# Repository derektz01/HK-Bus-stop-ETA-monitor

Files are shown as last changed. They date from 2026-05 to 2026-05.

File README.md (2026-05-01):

# HK Bus Stop ETA Monitor

Real-time Hong Kong bus arrival time display running on the **Waveshare ESP32-S3-Touch-LCD-4.3** — an all-in-one board with a 4.3" 800×480 IPS panel, capacitive touch (GT911), 16 MB flash, and 8 MB OPI PSRAM. ([https://www.waveshare.com/esp32-s3-touch-lcd-4.3.htm](https://www.waveshare.com/esp32-s3-touch-lcd-4.3.htm))

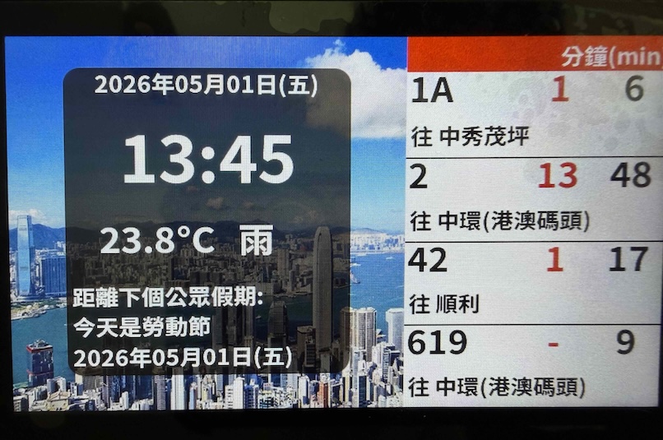
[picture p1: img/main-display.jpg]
Main Display


## Overview

This project turns the Waveshare ESP32-S3-Touch-LCD-4.3 board into a desk-side bus stop electronic arrival board. The UI is built with LVGL 8.4 (SquareLine Studio) directly on the on-board LCD — no external Nextion HMI required. All configuration lives on a captive web portal hosted by the device itself.

It fetches live ETA data from:

- KMB (九巴) — `data.etabus.gov.hk`
- Citybus (城巴) — `rt.data.gov.hk` (V1 batch endpoint)

Background changes through the day (day / sunset / night), and the panel can be put on a programmable sleep schedule with touch-wake.

The display shows:

- Current time, date, and weekday
- Hong Kong public holiday countdown
- Real-time temperature + weather icon (Open-Meteo)
- Up to 4 bus routes per page with smart ETA (`-`, `<1`, or minutes)
- Auto slideshow every 5 seconds; tap the right-side hotspot to advance manually

## Features

- **Multi-stop ETA** — pick any number of KMB and Citybus stops via the web UI; the device cycles through every selected stop on the slideshow.
- **Captive web settings portal** — Wi-Fi, stops, schedule, and language all configurable from a browser (`/api/config`, `/api/reboot` in [src/WebPortal.cpp](src/WebPortal.cpp)).
- **Map-based stop picker** — interactive Leaflet + OpenStreetMap view with all KMB / CTB stops as clickable pins. **No API key required**, all assets bundled in LittleFS.
- **Live "routes at this stop" view** — ⓘ button on every selected stop opens a modal listing every route that serves that stop, with destination. Live for KMB (via `/stop-eta/{id}`), cached for CTB.
- **Multi-language UI** — settings page in English or 繁體中文; auto-detects browser locale on first visit, persists choice in `localStorage`. Bus stop names always come from the API in Chinese (the underlying data).
- **Programmable sleep schedule** — repeating "wake at" / "sleep at" tasks per weekday; the device deep-sleeps between scheduled windows. Touch-wake grace period (1 / 2 / 5 / 10 / 30 minutes) lets the user glance at the screen mid-sleep.
- **Dynamic Citybus route/stop discovery** — no hardcoded route lists; the browser builds the full stop list once with a 60 s cooldown and a 2 h rate-limit gate to protect the upstream API.
- **AP-mode fallback** — device starts its own Wi-Fi AP if it can't join the configured network ([src/Wireless.cpp](src/Wireless.cpp)).
- **Smart ETA display** — `-` means arriving soon / not in service, `<1` means less than a minute, otherwise minutes. Both inbound and outbound directions shown when available.
- Routes auto-sorted by route number; destinations prefixed with `往` (toward) when present.
- Public holiday countdown loaded from `data/holiday.json`.
- NTP time sync (Hong Kong timezone, UTC+8).
- **PSRAM-bus optimised for the RGB panel** — internal-RAM ArduinoJson allocator, HTTP keep-alive for CTB, plain HTTP for KMB, field-filtered JSON parsing — all to keep the PSRAM bus quiet for the LCD scanout DMA so the panel doesn't drift during fetches.

## Hardware

- **Board**: [Waveshare ESP32-S3-Touch-LCD-4.3](https://www.waveshare.com/esp32-s3-touch-lcd-4.3.htm)
  - ESP32-S3-N16R8 (16 MB flash, 8 MB OPI PSRAM)
  - 4.3" 800×480 IPS panel via 16-bit RGB parallel interface
  - GT911 capacitive touch over I²C (INT on GPIO 4 — also the deep-sleep wake source)
  - CH422G IO expander (drives backlight, LCD reset, touch reset)
- **Power**: USB-C (5 V, ~400 mA)
- **No external display** — the LCD is on-board.

## Enclosure (3D-printed case)

A 3D-printable case with a desk stand has been designed for this build. The STEP sources are in the repo so you can adapt them in any CAD tool before slicing.

| Front | Back | Inside |
| --- | --- | --- |
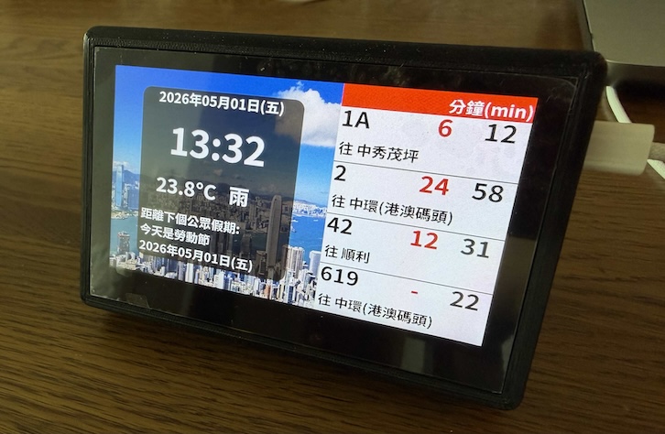
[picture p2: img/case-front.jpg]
Case front
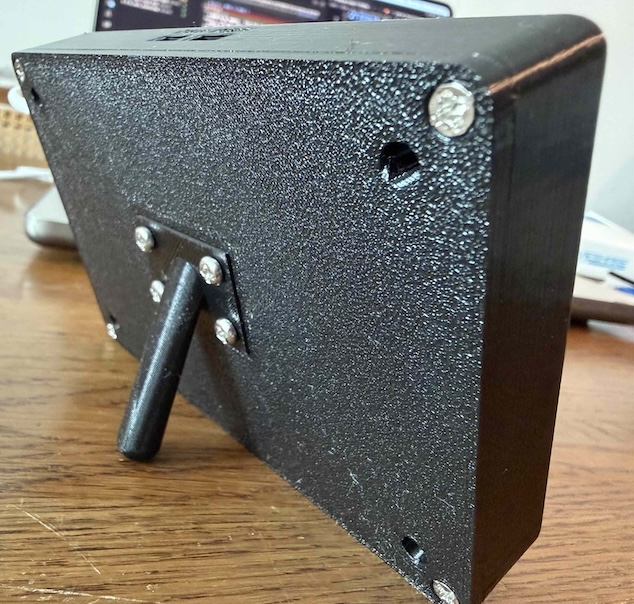
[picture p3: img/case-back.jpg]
Case back
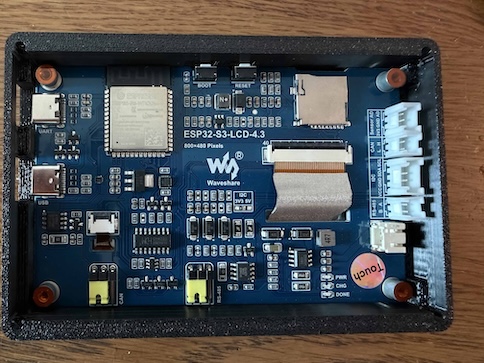
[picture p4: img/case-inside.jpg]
Inside
|  |  |  |

Download the STEP files from [`3D print/`](3D%20print/):

- [`ETA_Mon_Case.step`](3D%20print/ETA_Mon_Case.step) — main enclosure (front shell that holds the panel)
- [`ETA_Mon_Back_plate.step`](3D%20print/ETA_Mon_Back_plate.step) — rear plate covering the board
- [`ETA_Mon_Stand.step`](3D%20print/ETA_Mon_Stand.step) — desk stand

### Assembly hardware

You'll need a small set of screws to put it together:

- **4 × M2.5 × 6 mm Philips-head** — fix the Waveshare board to the back plate (the four mounting holes on the corners of the board)
- **8 × M3 × 4–5 mm flat-head countersunk** — clamp the front shell, back plate, and stand together

Any standard M2.5 / M3 hardware kit will have these. M3 × 4 mm or M3 × 5 mm both fit; longer than 5 mm risks bottoming out into the panel cavity.

## Repository Structure

```text
include/
└── esp_panel_board_custom_conf.h   # ESP32_Display_Panel board config
src/
├── main.cpp                # setup(), loop(), networkTask, webPortalTask
├── Display.cpp / .h        # LVGL widget glue (Update_Time, Update_Bus_List, ...)
├── lvgl_v8_port.cpp / .h   # LVGL ↔ ESP32_Display_Panel adapter
├── ui/                     # SquareLine Studio generated UI
│   ├── ui_Main.c           # Widget tree
│   ├── ui_font_NSTC*.c     # NotoSans TC fonts (28/44/80 px)
│   └── ui_img_*.c          # Background images (day / sunset / night)
├── BusData.cpp / .h        # KMB + Citybus ETA fetching
├── WeatherData.cpp / .h    # Open-Meteo weather
├── HolidayData.cpp / .h    # Holiday JSON loading + countdown
├── ConfigManager.cpp / .h  # Persisted config (Wi-Fi, stops, schedule)
├── Wireless.cpp / .h       # Wi-Fi STA + AP-mode fallback
├── WebPortal.cpp / .h      # HTTP server: /api/config, /api/reboot, static
├── Sleep.cpp / .h          # Deep-sleep scheduler + GT911 touch wake
├── JsonInternal.h          # Internal-RAM ArduinoJson allocator
└── Diagnostics.cpp / .h    # Heap_Log helper
data/
├── index.html              # Captive web settings portal
├── favicon.ico             # 32×32 favicon
├── leaflet.{js,css}        # Leaflet 1.9.4 (bundled, no CDN)
├── leaflet.markercluster.js
├── MarkerCluster*.css
├── config.json             # Runtime config (created from .template)
└── holiday.json            # 2026 Hong Kong public holidays
partitions_16MB_littlefs.csv  # Custom 16 MB partition (7 MB app × 2 + 2 MB FS)
```

## Dependencies

PlatformIO libraries (pinned in `platformio.ini`):

- [`ESP32_Display_Panel`](https://github.com/esp-arduino-libs/ESP32_Display_Panel) — board / panel / touch driver
- [`ESP32_IO_Expander`](https://github.com/esp-arduino-libs/ESP32_IO_Expander) — CH422G driver
- `esp-arduino-libs/esp-lib-utils @ ^0.3.0`
- `lvgl/lvgl @ ^8.4.0`
- `bblanchon/ArduinoJson @ ^7.2.0`

## Configuration

Everything except the AP credentials is configured at runtime through the captive web portal — see [TUTORIAL.md](TUTORIAL.md) for a full walkthrough.

### Bootstrap config (one-time, before first flash)

Before flashing, seed the device with at least the **AP credentials** so you can reach the captive portal when it falls back to AP mode.

1. Rename the template:

   ```bash
   cp data/config.json.template data/config.json
   ```

2. Edit `data/config.json`:

   ```jsonc
   {
     "wifi": {
       "ssid": "YOUR_WIFI_SSID",         // optional — set later in the portal
       "password": "YOUR_WIFI_PASSWORD"  // optional
     },
     "ap": {
       "ssid": "BusETAMonitor-AP",       // REQUIRED
       "password": "12345678"            // REQUIRED — ≥ 8 characters
     },
     "stops": {
       "kmb": [],                        // optional — pick stops in the portal
       "ctb": []
     },
     "sleep_schedule": {
       "wake_tasks": [],                 // optional — set in the portal
       "sleep_tasks": [],
       "grace_period_minutes": 5
     }
   }
   ```

3. Upload to LittleFS:

   ```bash
   pio run -t uploadfs
   ```

   The same command also uploads `index.html`, `holiday.json`, the Leaflet bundle, and the favicon — re-run any time you edit anything under `data/`.

> `data/config.json` is your local secrets file (it can hold your home Wi-Fi password). It is **not** intended to be committed to the repo — only `data/config.json.template` should be tracked.

### First boot

If the device cannot join the saved Wi-Fi (or none is configured), it falls back to AP mode. Connect your phone or laptop to the AP advertised by the device, then open `http://192.168.4.1` in a browser.

Once the device is on your home Wi-Fi, the same page is reachable at the device's IP, which the LCD displays in a scrolling banner for 2 minutes after every boot.

## Build & Upload

```bash
# 1. Upload data/ to LittleFS (settings page, leaflet, favicon, holidays)
pio run -t uploadfs

# 2. Build & upload firmware
pio run -t upload

# 3. Build only
pio run

# Optional — wipe flash (e.g. after changing the partition table)
pio run -t erase
```

The custom partition table `partitions_16MB_littlefs.csv` provides 7 MB per app slot (dual OTA) + ~2 MB LittleFS. If you change it, run `pio run -t erase` once before the next upload so the bootloader re-reads the partition map.

## Notes

- Slideshow advances every **5 seconds**. Tap the right-side hotspot on the panel to advance manually.
- Wi-Fi info banner shows on the LCD for **2 minutes** after every boot, then auto-hides.
- If Wi-Fi fails, the board keeps running with the last cached ETAs; weather + ETA fetches resume automatically when the link returns.
- Holiday display refreshes once per hour; backgrounds switch at 06:00 (day), 17:00 (sunset), 18:30 (night).
- Weather refreshes every 30 minutes; bus ETAs every 45 seconds.
- The deep-sleep scheduler wakes from either a configured timer or a screen touch (GT911 INT on GPIO 4).

## License

This project is released under the **Creative Commons Attribution-NonCommercial 4.0 International** licence ([CC BY-NC 4.0](https://creativecommons.org/licenses/by-nc/4.0/)).

You are free to:

- **Use, copy, modify, and redistribute** the source, the 3D-printable STEP files, and the documentation,
- for **personal, educational, and other non-commercial** purposes,
- as long as you give appropriate credit (link back to this repo).

You **may not** use this work — in whole or in part — for **commercial** purposes (selling assembled units, paid services built on this code, or any other commercial offering) without prior written permission from the author. If you'd like to discuss a commercial use, please open an issue first.

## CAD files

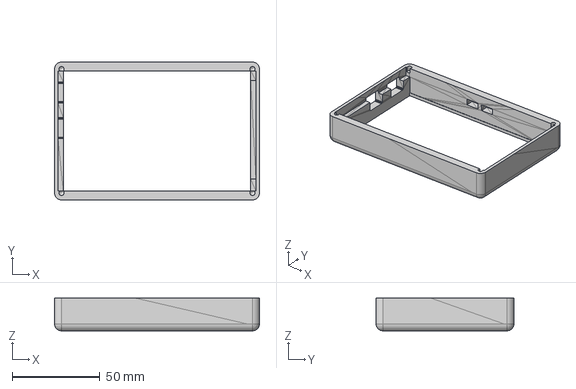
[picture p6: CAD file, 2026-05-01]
3D print/ETA_Mon_Case.step
116.5 x 78.4 x 18.6 mm

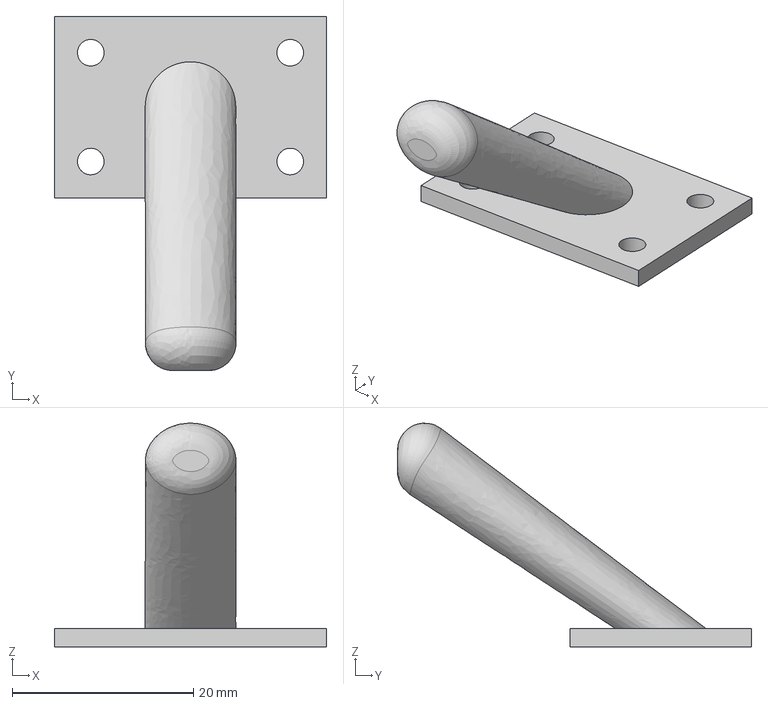
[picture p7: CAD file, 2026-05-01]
3D print/ETA_Mon_Stand.step
30.0 x 39.1 x 24.7 mm

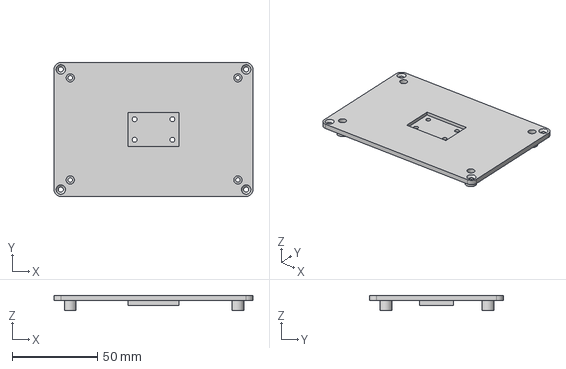
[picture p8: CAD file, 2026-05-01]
3D print/ETA_Mon_Back_plate.step
116.5 x 78.4 x 9.00 mm

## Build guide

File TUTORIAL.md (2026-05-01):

# Web Settings Page — User Guide

A walkthrough of the captive web portal used to configure the HK Bus ETA Monitor: language, Wi-Fi, the stop list cache, three ways to pick bus stops, the routes-at-stop view, the sleep schedule, save / reboot, and the rebuild cooldown / rate-limit gate.

---

## 1. Opening the settings page

The device serves the settings page on port 80 in both Wi-Fi modes:

- **First boot or after a Wi-Fi join failure** — the device falls back to AP mode (see [src/Wireless.cpp](src/Wireless.cpp)). Connect your phone or laptop to the AP advertised by the device, then open `http://192.168.4.1`.
- **Normal operation** — the device joins your home Wi-Fi as a station. Open `http://<device-ip>` (the IP appears on the device's LCD — see below).

### Finding the IP on the LCD

The firmware shows a **scrolling Wi-Fi info banner** on the LCD for the first **2 minutes** after every boot:

- **STA mode**: `WiFi:<ssid>  IP:<ip>`
- **AP mode**: `AP:<ssid>  P:<password>  IP:<ip>`

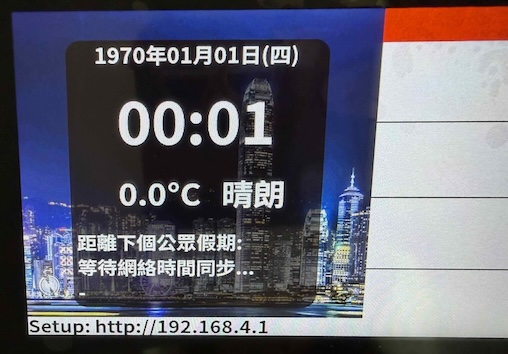
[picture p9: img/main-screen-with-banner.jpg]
Device LCD showing the Wi-Fi info banner


After 2 minutes the banner disappears so it doesn't clutter the ETA display. If you miss it, just power-cycle the device — the banner reappears for another 2 minutes after every boot.

You should see the page below.

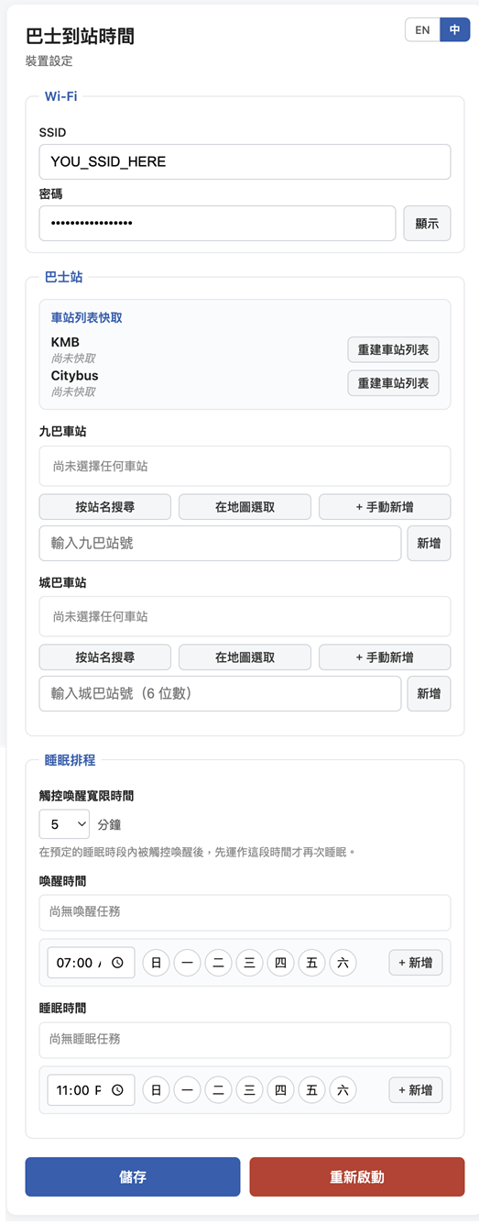
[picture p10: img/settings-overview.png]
Settings page overview


---

## 2. Switching language

The top-right of the card has a small **EN / 中** toggle. The page auto-detects your browser's language on first visit (anything starting with `zh` → 繁體中文, otherwise English) and persists your choice in `localStorage`.

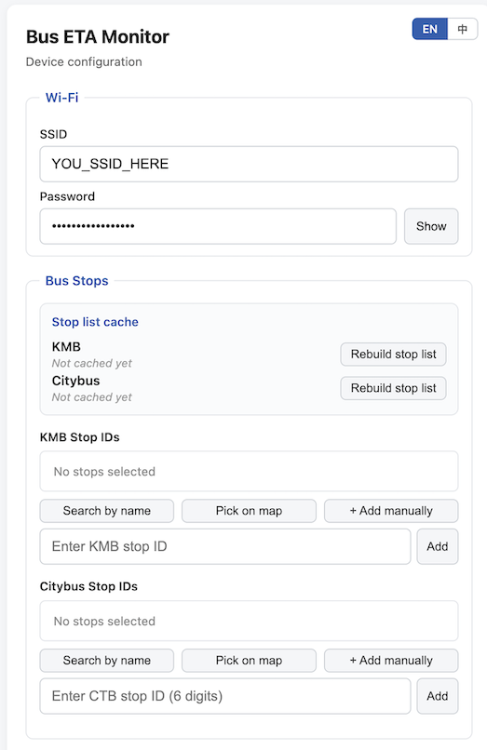
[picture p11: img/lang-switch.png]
Language switcher in the top-right of the card


> Bus stop names are **not** translated — they always come from the operator's API in Chinese (the source field is `name_tc`). Only the UI chrome flips when you switch language.

---

## 3. Wi-Fi setup

Fill in the **SSID** and **Password** of the network you want the device to join. Click **Show** next to the password to reveal what you typed; click **Hide** to mask it again.

> Wi-Fi changes do **not** take effect immediately — you must press **Save** and then **Reboot** before the device tries the new credentials.

---

## 4. Stop list cache

> ⚠️ **Wi-Fi (STA) mode is required to build the cache.** The cache build runs entirely in **your browser** — it fetches stop data straight from `data.etabus.gov.hk` and `rt.data.gov.hk`, not through the device. While the device is in **AP mode**, your phone or laptop has no path to the public internet, so the rebuild will fail (you'll see a CORS-looking error in the console; it's actually `HTTP 403` from the upstream gateway).
>
> **First-time setup flow**:
>
> 1. Complete [§3 Wi-Fi setup](#3-wi-fi-setup) — enter your home Wi-Fi SSID + password.
> 2. Click **Save**, then click **Reboot** ([§10](#10-rebooting-the-device)).
> 3. After the device comes back, the LCD banner ([§1](#1-opening-the-settings-page)) shows the new STA IP. Reconnect a browser on the **same home Wi-Fi** to that IP.
> 4. *Now* you can press **Rebuild stop list** here.

A separate **Stop list cache** card sits at the top of the Bus Stops section. It shows, at a glance:

- Whether the cache is built for each operator
- The total stop count and last-built timestamp
- A **Rebuild stop list** button per operator with the same 60 s cooldown and 2 h rate-limit gate (see §8)

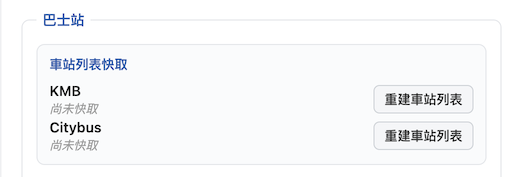
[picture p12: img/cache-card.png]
Stop list cache card


To use search or map-based stop picking, you need the cache built. KMB ships its full stop list at one endpoint (~6,800 stops, ~5 s build); CTB has no single endpoint, so the page builds it in three phases:

1. Fetch the route list (`/route/CTB`)
2. For each route × direction, fetch the route-stop list
3. For each unique stop, fetch the stop name + coordinates + per-route metadata

Expect CTB's first build to take a few minutes. Watch progress in the per-row status line.

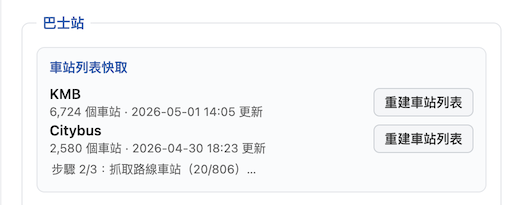
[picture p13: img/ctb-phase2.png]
CTB rebuild — Phase 2/3 in progress


The cache is stored in your browser's `localStorage` — it's a one-time cost per browser. Both caches now also carry stop coordinates (used by the map view) and CTB carries per-stop route info (used by the routes-at-stop view).

---

## 5. Picking bus stops

Each operator (KMB and Citybus) has the same row of three buttons under its label:

| Button | What it does |
| --- | --- |
| **Search by name** | Type any part of the Chinese stop name; live results from the cache. |
| **Pick on map** | Open an interactive map — pan / zoom, tap any pin to add. |
| **+ Add manually** | Type a known stop ID directly. Useful if you copied it from a URL. |

You can mix all three. Selected stops appear in the list above the buttons; click the red **×** on a row to remove a stop, click **ⓘ** to view the routes that serve it (see §6).

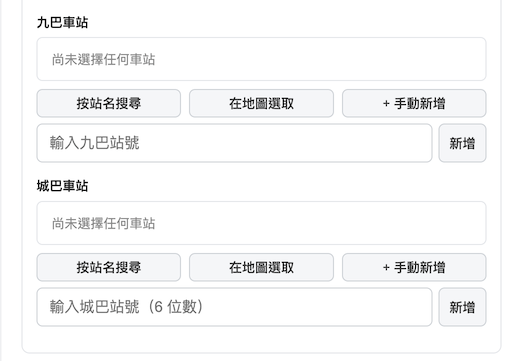
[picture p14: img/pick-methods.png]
Three pick methods, all visible


### 5a. Search by name

Open the search panel with **Search by name**, type any substring of the Chinese stop name, click any row to add.

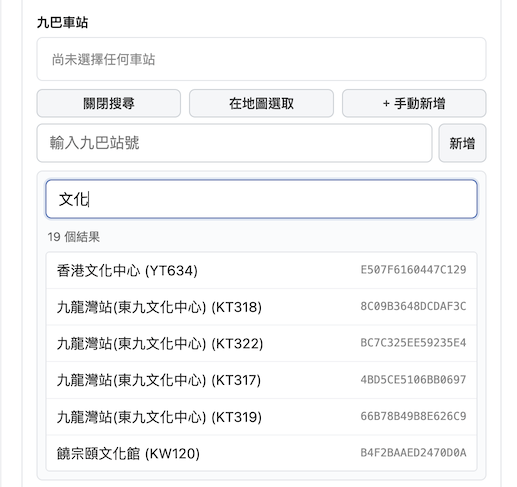
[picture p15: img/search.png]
KMB search results


You can add **as many stops as you want** for both KMB and Citybus — the device cycles through every selected stop on the slideshow.

### 5b. Pick on map (new)

Open with **Pick on map**. The map opens centred on Hong Kong with all stops as clustered pins (numbered cluster bubbles when zoomed out, individual pins when zoomed in). Tap a pin → a popup shows the stop name and ID with **Add this stop** and **View routes** buttons.

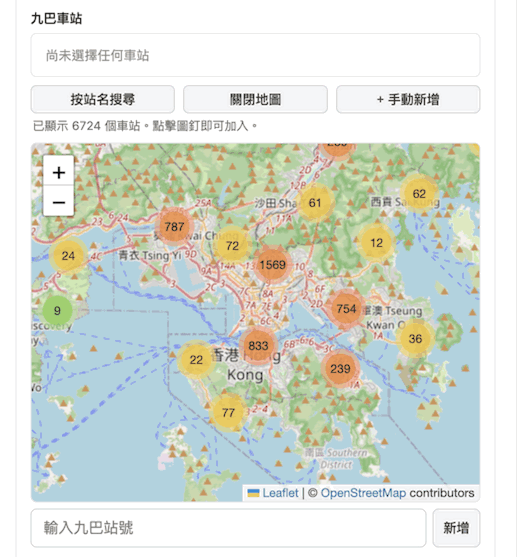
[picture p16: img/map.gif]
Map picker


The map uses Leaflet + OpenStreetMap tiles — **no API key required**, but the browser does need internet for the tile downloads. The Leaflet library itself is bundled in LittleFS.

> Already-selected stops appear in green on the map; unselected pins are blue. If tiles fail to load (e.g. you're connected only to the device's AP), a banner appears suggesting you fall back to **Search by name**.

### 5c. Add manually

Click **+ Add manually** under the operator section, type the stop ID, click **Add**.

- KMB IDs look like `904DEAF7441E3BB8` (16-char hex).
- CTB IDs are 6 digits, e.g. `001027`.

Manually-added stops show "(unresolved)" until the relevant cache is built — but they still work; the firmware queries by ID, not by name.

---

## 6. Viewing routes for a stop (new)

Each row in your selected-stops list has an **ⓘ** button (between the stop name and the red **×**). Click it to see every route that serves that stop, with destination.

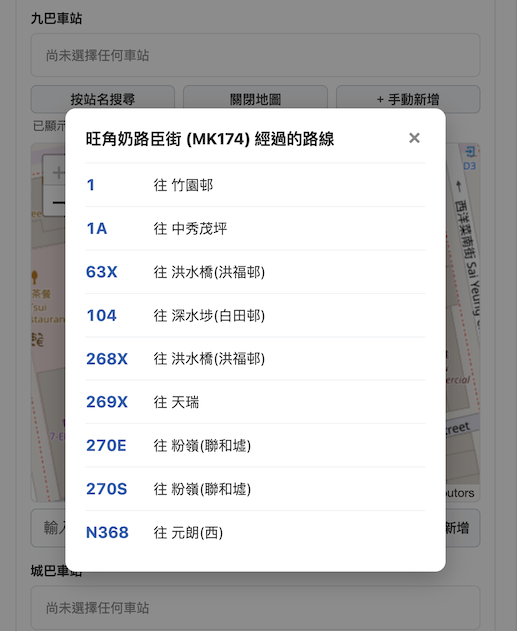
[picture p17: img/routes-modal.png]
View-routes modal


- For **KMB**, this fetches `/v1/transport/kmb/stop-eta/<id>` live, so the route list reflects current service.
- For **CTB**, this reads from the cache built earlier (CTB has no per-stop ETA endpoint that returns routes; you need the cache up-to-date — if it isn't, the modal tells you to rebuild first).

The same modal opens from the map popup's **View routes** button.

---

## 7. Sleep schedule (new)

A separate **Sleep Schedule** fieldset configures when the device deep-sleeps and wakes:

- **Touch-wake grace period** — when you tap the screen during a scheduled sleep window, the device wakes up and runs for this long before re-sleeping. Choices: 1 / 2 / 5 / 10 / 30 minutes.
- **Wake at** — list of repeating times the device should wake. Each task is `HH:MM` plus a set of weekdays (日 一 二 三 四 五 六).
- **Sleep at** — list of repeating times the device should enter deep sleep.

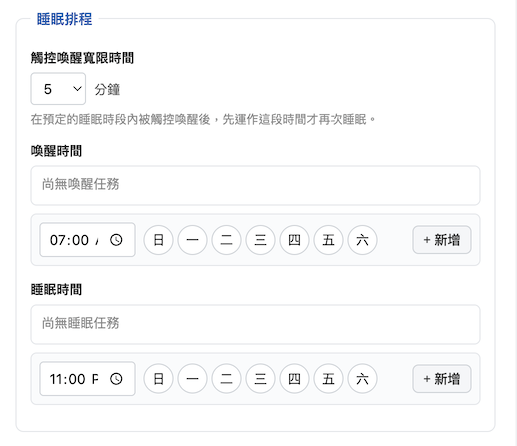
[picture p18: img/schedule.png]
Sleep schedule UI


Click the day circles to toggle weekdays (blue = active). Click **+ Add** to commit a task to the list; click the red **×** on a row to remove it.

### How the schedule is interpreted

The device computes the most recent past sleep-task and the most recent past wake-task. If the most recent event was a sleep, it deep-sleeps until the next wake-task time. If the most recent event was a wake, it runs until the next sleep-task time.

Touch-wake during a sleep window grants you the configured grace period before the device re-sleeps — handy for a quick glance.

> Schedule changes do **not** require a reboot — they're picked up on the next loop tick. Wi-Fi changes still do.

---

## 8. Rebuild cooldown and rate-limit gate

The KMB and Citybus APIs both rate-limit aggressive callers. The page has two protections.

### 60-second cooldown

After every rebuild — successful or failed — the **Rebuild stop list** button is disabled for 60 seconds and shows a live countdown:

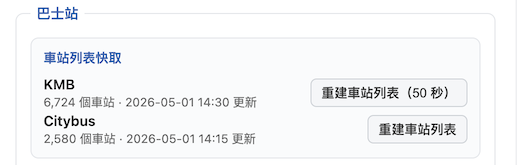
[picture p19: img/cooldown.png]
Rebuild button in cooldown


This applies to KMB and CTB independently.

### 2-hour cache-age gate

If you click **Rebuild stop list** while the cache is younger than 2 hours, a confirm dialog tells you exactly how recent the cache is and warns about API rate-limiting:

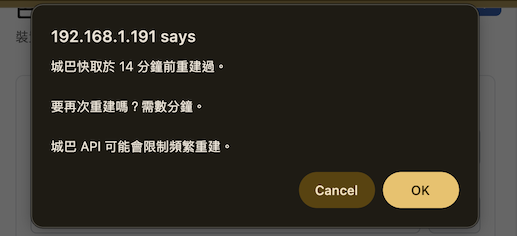
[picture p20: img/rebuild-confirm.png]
Cache-age warning


> **Why this matters.** When `data.gov.hk` rate-limits a request it returns `HTTP 403` *without* CORS headers. The browser surfaces this as a confusing CORS error in the console even though the real cause is throttling. The cooldown and gate are there so you don't trip into that state by accident.

Stop lists rarely change — rebuild only when you genuinely need newer data (e.g. a new route opened).

---

## 9. Saving configuration

Click **Save** to persist Wi-Fi credentials, the selected stop lists, and the sleep schedule to flash. The page POSTs to `/api/config` and the firmware writes to LittleFS ([src/WebPortal.cpp](src/WebPortal.cpp)).

| Change | Takes effect |
| --- | --- |
| Stop selection | next ETA refresh (≤ 45 s) — no reboot |
| Sleep schedule (incl. grace period) | next loop tick — no reboot |
| Wi-Fi credentials | requires **Reboot** |

---

## 10. Rebooting the device

Click **Reboot** and confirm:

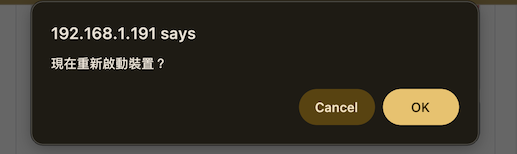
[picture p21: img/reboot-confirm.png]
Reboot confirmation


The page shows a 5-second countdown and refreshes itself when the device comes back up:

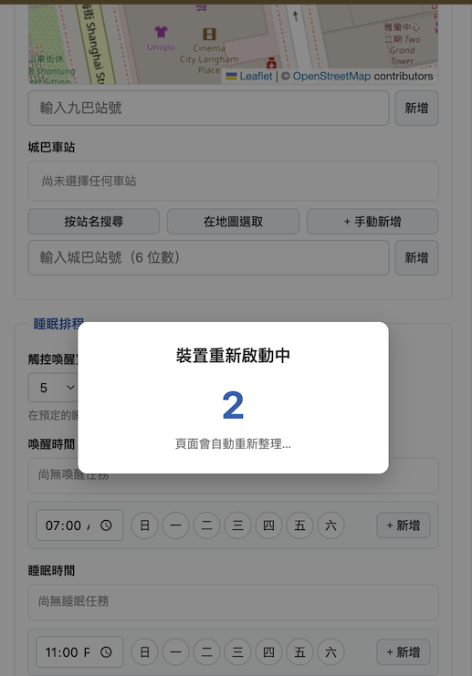
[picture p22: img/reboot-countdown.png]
Reboot countdown


If you changed Wi-Fi credentials, the device may now be on a different network — re-open the page at the new IP shown on the LCD (the banner reappears for 2 minutes after every boot).

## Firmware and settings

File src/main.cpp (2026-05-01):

#include <Arduino.h>
#include "Display.h"
#include "Diagnostics.h"
#include "BusData.h"
#include "WiFi.h"
#include "WeatherData.h"
#include "HolidayData.h"
#include "ConfigManager.h"
#include "Wireless.h"
#include "WebPortal.h"
#include "Sleep.h"

// Set true by network task while an API fetch is in progress; gates the loop
// task's UI work to free PSRAM bandwidth for the LCD EDMA. Single writer
// (network task), multiple readers — volatile is sufficient on ESP32-S3.
volatile bool g_apiFetchInProgress = false;

void printLocalTime()
{
  struct tm timeinfo;
  if (!getLocalTime(&timeinfo))
  {
    printf("Failed to obtain time");
    return;
  }
  printf("%A, %B %d %Y %H:%M:%S", &timeinfo); // Formatted print
}

// All HTTP/TLS work runs on core 0 (the WiFi core). Keeps the LCD-driving
// LVGL task on core 1 free of WiFi-DMA + JSON-parsing PSRAM contention,
// which previously caused horizontal drift during fetches.
static bool isWallClockValid()
{
  // 1577836800 = 2020-01-01 00:00:00 UTC. Anything earlier means SNTP hasn't
  // delivered a real timestamp yet (the system is still on the 1970 epoch).
  return time(nullptr) > 1577836800;
}

// Pinned to core 0 so HTTP-portal request handling (config save / reboot /
// static asset reads) doesn't preempt the LVGL render task on core 1 during
// a request. Polls handleClient() with a short delay to keep CPU low when
// idle. 8 KB stack covers the JSON parse + HTML response paths.
static void webPortalTask(void *)
{
  for (;;)
  {
    WebPortal_Loop();
    vTaskDelay(pdMS_TO_TICKS(20));
  }
}

static void networkTask(void *)
{
  // Wait for WiFi to come up before the first fetch.
  while (!WiFi_IsConnected())
  {
    vTaskDelay(pdMS_TO_TICKS(500));
  }

  // If setup() couldn't finish NTP in 15 s, keep waiting here. A fetch with
  // epoch time would produce wrong "minutes-until-bus" values everywhere.
  while (!isWallClockValid())
  {
    printf("networkTask: deferring first fetch — wall clock still pre-2020 (NTP not synced)\n");
    vTaskDelay(pdMS_TO_TICKS(2000));
  }

  // Wall clock is now valid. Re-paint everything that depends on time —
  // setup() may have run these while NTP was still pre-2020 (showing
  // 1970-01-01, "還有999天", wrong day/night background, etc.). Each call
  // is cheap thanks to change-detection; if the value is already correct
  // it returns before touching LVGL.
  Update_Time();
  vTaskDelay(pdMS_TO_TICKS(500));
  Update_Date_And_Weekday();
  vTaskDelay(pdMS_TO_TICKS(500));
  Update_Holiday_Display();
  vTaskDelay(pdMS_TO_TICKS(500));
  Update_Background();
  vTaskDelay(pdMS_TO_TICKS(500));
  Weather_FetchOpenMeteo();
  vTaskDelay(pdMS_TO_TICKS(500));
  {
    const Config &cfg = ConfigMgr.getConfig();
    AutoRefreshBusETA(cfg.kmb_stop_ids, cfg.ctb_stop_ids);
    vTaskDelay(pdMS_TO_TICKS(500));
  }

  uint32_t lastBus     = millis();
  uint32_t lastWeather = millis();

  for (;;)
  {
    if (WiFi_IsConnected())
    {
      uint32_t now = millis();
      if (now - lastBus >= 45000)
      {
        const Config &cfg = ConfigMgr.getConfig();
        AutoRefreshBusETA(cfg.kmb_stop_ids, cfg.ctb_stop_ids);
        vTaskDelay(pdMS_TO_TICKS(1000));
        lastBus = millis();
      }
      if (now - lastWeather >= 1800000)
      {
        Weather_FetchOpenMeteo();
        vTaskDelay(pdMS_TO_TICKS(500));
        lastWeather = millis();
      }
    }
    vTaskDelay(pdMS_TO_TICKS(500));
  }
}

void setup()
{
  Serial.begin(115200);
  delay(800);

  // Log why this boot happened (power-on vs. timer-wake vs. touch-wake).
  Sleep_Init();

  // Brings up the Waveshare ESP32-S3-Touch-LCD-4.3 board, LVGL, and the
  // SquareLine UI. Must run before any Update_* / ShowWifiInfo call.
  Display_Init();

  // Load configuration from LittleFS
  ConfigMgr.load();

  // === Centralized WiFi handling ===
  WiFi_Connect();
  Heap_Log("after WiFi_Connect");

  // Start configuration web server (works in both AP and STA mode)
  WebPortal_Begin();

  // Sync time if connected
  if (WiFi_IsConnected())
  {
    // Sync time with NTP (Hong Kong timezone UTC+8). configTime() only kicks
    // off the SNTP daemon — it doesn't wait for a response. Block here for up
    // to 15 s so subsequent fetches (which compute ETAs against `time(nullptr)`)
    // don't run with epoch (1970-01-01) and produce nonsense minutes.
    configTime(8 * 3600, 0, "pool.ntp.org", "time.google.com");
    printf("NTP Time Sync started (UTC+8); waiting up to 15s for first response...\n");

    struct tm timeinfo;
    if (getLocalTime(&timeinfo, 15000))
    {
      printf("NTP synced: %04d-%02d-%02d %02d:%02d:%02d\n",
             timeinfo.tm_year + 1900, timeinfo.tm_mon + 1, timeinfo.tm_mday,
             timeinfo.tm_hour, timeinfo.tm_min, timeinfo.tm_sec);
    }
    else
    {
      printf("WARNING: NTP not synced after 15s. networkTask will defer the first fetch until time is valid.\n");
    }
  }

  // Initialize bus data
  BusData_Init();

  // Initialize holiday data
  Holiday_Init();

  // Show initial full display
  Update_Time();
  Update_Date_And_Weekday();
  Update_Weather();
  Update_Holiday_Display();
  Update_Background();
  ShowWifiInfo();

  // Spin up the network task on core 0. Weather + bus fetches happen there
  // on their own cadence; the Arduino loop on core 1 only drives UI ticks.
  xTaskCreatePinnedToCore(networkTask, "network", 12 * 1024, nullptr, 1, nullptr, 0);

  // WebPortal HTTP polling on core 0 too — keeps it off core 1 alongside
  // the network task. Both are I/O-bound and yield often, so they coexist
  // without starving each other.
  xTaskCreatePinnedToCore(webPortalTask, "webportal", 8 * 1024, nullptr, 1, nullptr, 0);

  printf("HK Bus Stop ETA Board Ready!\r\n");
}

void loop()
{
  static unsigned long lastTimeUpdate = 0;
  static unsigned long lastSlideshow = 0;
  static unsigned long lastHolidayUpdate = 0;
  static unsigned long lastBackgroundCheck = 0;
  static unsigned long lastWifiInfoCycle = 0;
  static unsigned long bootTime = millis();
  static bool wifiInfoHidden = false;

  // Test-only: enter deep sleep at uptime+3min, wake after 6min (or touch).
  // Never returns once the threshold is hit; the device reboots on wake.
  Sleep_Tick();

  // WebPortal polling lives on core 0 (see webPortalTask) so the LVGL task
  // on core 1 never has to share with HTTP-portal request handling.

  // While the network task is mid-fetch, skip everything that would dirty an
  // LVGL widget (which forces a full-frame PSRAM write and contends with the
  // LCD EDMA scanout). Resumes immediately when the fetch finishes; pending
  // ticks (time, slideshow) catch up on the next loop iteration.
  if (g_apiFetchInProgress)
  {
    delay(200);
    return;
  }

  if (!wifiInfoHidden && (millis() - bootTime > 120000))
  { // 120 seconds
    HideWifiInfo();
    wifiInfoHidden = true;
  }

  // While the wifi-info banner is visible, rotate it through its frames every
  // 5 s so the user can read the SSID, password (AP mode), and the setup URL
  // without needing a scrolling animation.
  if (!wifiInfoHidden && (millis() - lastWifiInfoCycle > 5000))
  {
    lastWifiInfoCycle = millis();
    Cycle_Wifi_Info();
  }

  // Update time every second
  if (millis() - lastTimeUpdate > 1000)
  {
    lastTimeUpdate = millis();
    Update_Time();
    Update_Date_And_Weekday();
  }

  // Update holiday info every hour
  if (millis() - lastHolidayUpdate > 3600000)
  { // 1 hours
    lastHolidayUpdate = millis();
    Update_Holiday_Display();
  }

  // Update background picture every 15 minutes (only sends on change)
  if (millis() - lastBackgroundCheck > 90000)
  {
    lastBackgroundCheck = millis();
    Update_Background();
  }

  // Weather + bus ETA fetches now run on the core-0 networkTask (see setup),
  // not from this loop. Removed to keep WiFi/HTTP off the LCD-driving core.

  // Auto slideshow every 5 seconds
  if (millis() - lastSlideshow > 5000)
  {
    lastSlideshow = millis();
    Switch_To_Next_Page();
    Update_Bus_List();
  }

  // Touch is handled by ui_event_ctrTouch → NextPage() → OnNextPagePressed()
  delay(10);
}

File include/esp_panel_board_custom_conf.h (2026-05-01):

/*
 * SPDX-FileCopyrightText: 2023-2025 Espressif Systems (Shanghai) CO LTD
 *
 * SPDX-License-Identifier: Apache-2.0
 */
/**
 * @file   esp_panel_board_custom_conf.h
 * @brief  Configuration file for custom ESP development boards
 * @author
 * @link
 *
 * This file contains all the configurations needed for a custom board using ESP Panel.
 * Users can modify these configurations according to their hardware design.
 */

#pragma once

// *INDENT-OFF*
#define ESP_OPEN_TOUCH 1 // 1 initiates the touch, 0 closes the touch.

/**
 * @brief Flag to enable custom board configuration (0/1)
 *
 * Set to `1` to enable custom board configuration, `0` to disable
 */
#define ESP_PANEL_BOARD_DEFAULT_USE_CUSTOM  (1)

#if ESP_PANEL_BOARD_DEFAULT_USE_CUSTOM
////////////////////////////////////////////////////////////////////////////////////////////////////////////////////////
///////////////////////// Please update the following macros to configure general parameters ///////////////////////////
////////////////////////////////////////////////////////////////////////////////////////////////////////////////////////
/**
 * @brief Board name (format: "Manufacturer:Model")
 */
#define ESP_PANEL_BOARD_NAME                "Waveshare:ESP32-S3-Touch-LCD-4.3"

/**
 * @brief Panel resolution configuration in pixels
 */
#define ESP_PANEL_BOARD_WIDTH               (800)   // Panel width (horizontal, in pixels)
#define ESP_PANEL_BOARD_HEIGHT              (480)   // Panel height (vertical, in pixels)

////////////////////////////////////////////////////////////////////////////////////////////////////////////////////////
//////////////////////////// Please update the following macros to configure the LCD panel /////////////////////////////
////////////////////////////////////////////////////////////////////////////////////////////////////////////////////////
/**
 * @brief LCD panel configuration flag (0/1)
 *
 * Set to `1` to enable LCD panel support, `0` to disable
 */
#define ESP_PANEL_BOARD_USE_LCD             (1)

#if ESP_PANEL_BOARD_USE_LCD
/**
 * @brief LCD controller selection
 */
#define ESP_PANEL_BOARD_LCD_CONTROLLER      ST7262

/**
 * @brief LCD bus type selection
 */
#define ESP_PANEL_BOARD_LCD_BUS_TYPE        (ESP_PANEL_BUS_TYPE_RGB)


/**
 * @brief LCD bus parameters configuration
 *
 * Configure parameters based on the selected bus type. Parameters for other bus types will be ignored.
 * For detailed parameter explanations, see:
 * https://docs.espressif.com/projects/esp-idf/en/v5.3.1/esp32s3/api-reference/peripherals/lcd/index.html
 * https://docs.espressif.com/projects/esp-iot-solution/en/latest/display/lcd/index.html
 */
#if ESP_PANEL_BOARD_LCD_BUS_TYPE == ESP_PANEL_BUS_TYPE_RGB

    /**
     * @brief RGB bus
     */
    /**
     * Set to 0 if using simple "RGB" interface which does not contain "3-wire SPI" interface.
     */
    #define ESP_PANEL_BOARD_LCD_RGB_USE_CONTROL_PANEL       (0) // 0/1. Typically set to 1
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

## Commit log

2026-04-24 feat: Implement bus ETA functionality with KMB and Citybus support
    - Added BusData module for handling bus route information and ETA calculations.
    - Introduced ConfigManager for managing configuration settings, including WiFi and bus stop IDs.
    - Integrated weather data fetching from Open-Meteo API and display updates on Nextion.
    - Developed WebPortal for configuration management via HTTP requests.
    - Implemented holiday data handling and display logic.
    - Created Wireless module for WiFi connection management and AP mode handling.
    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
2026-04-24 feat: Add bootstrap configuration instructions for initial device setup
2026-04-30 refactor: Implement recursive mutex for thread-safe access to displayRoutes and currentPage
2026-04-30 Enhance bus ETA fetching and display updates
    - Increased delay between fetching bus ETA for KMB and Citybus from 100ms to 200ms to reduce server load.
    - Added a check for wall clock synchronization in holiday display updates to prevent incorrect date displays.
    - Implemented a cycling mechanism for the Wi-Fi info banner to display short frames instead of scrolling text, improving readability and reducing PSRAM bandwidth contention.
    - Added new functions to retrieve Wi-Fi info frames based on connection mode (AP or STA) and updated the display logic accordingly.
    - Updated web portal to serve additional static files for leaflet.js and related styles.
    - Ensured that time-dependent displays are u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
2026-04-30 Refactor code structure for improved readability and maintainability
    [partitions_16MB_littlefs.csv]
2026-04-30 feat: Add field filters for bus ETA and weather data to reduce memory usage
2026-05-01 Update README and TUTORIAL for Waveshare ESP32-S3-Touch-LCD-4.3 integration; enhance features and UI descriptions
    - Updated project description in README to reflect the use of Waveshare ESP32-S3-Touch-LCD-4.3.
    - Enhanced feature list with new capabilities including multi-stop support, map-based stop picker, and sleep schedule configuration.
    - Revised repository structure and dependencies for clarity.
    - Improved configuration instructions in TUTORIAL, including language switching and cache management.
    - Removed outdated images and added new images for better visual representation.
    [ETA_Mon_Back_plate.step, ETA_Mon_Case.step, ETA_Mon_Stand.step]
2026-05-01 feat: Update README and TUTORIAL with additional details; add case interior image
2026-05-01 docs: Add assembly hardware requirements to README
